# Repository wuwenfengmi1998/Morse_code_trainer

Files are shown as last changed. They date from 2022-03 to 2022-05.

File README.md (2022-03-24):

仓库地址 [Github][1]  
备用仓库 [Git.LMVE][2]  
# 莫尔斯电码练习器

## 项目背景
对业余无线电产生了一些兴趣，想学习莫尔斯电码。买一个练习器太贵了，所以打算做一个。

# 开发中
## 硬件&功能
* STM32L03x 32PinIO 48MHz 
* Buzzer 带静音电路
* 3.5 Audio接口 输入与输出 输出电容耦合
* 12864OLED
* EEPROM
* 编码器开关 开机电路
* TYPEC USB 充放电路 带串口芯片
* 电池 电量检测电路

## 软件功能
* 基础UI
* 莫尔斯电码输入识别 手动键与自动键
* 蜂鸣器播放 音频口输出 可静音
* 可设置速率
* 电池电量检测

  [1]: https://github.com/wuwenfengmi1998/Morse_code_trainer
  [2]: https://git.lmve.net/kevin/morse_code_trainer

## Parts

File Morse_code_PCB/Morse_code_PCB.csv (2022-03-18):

ID | 指示符 | 软件包 | 数量 | 名称 | 供应商和参考
1 | C2,C3 | C_0603_1608Metric | 2 | 10nF
2 | R19,R21,R20,R18,R17,R2,R16,R3,R4 | R_0603_1608Metric | 9 | 10K
3 | C4,C9,C7,C11 | C_0805_2012Metric | 4 | 104
4 | Q3,Q1 | SOT-23 | 2 | AO3400A
5 | BZ1 | Buzzer_TDK_PS1240P02BT_D12.2mm_H6.5mm | 1 | Buzzer
6 | J4 | SIP-2 | 1 | Conn_01x02_Female
7 | D1,D5,D4 | D_SOD-523 | 3 | 1N4148WT
8 | D2,D3,D6 | LED_0603_1608Metric | 3 | LED
9 | R8,R7,R6,R9 | R_0603_1608Metric | 4 | 20K
10 | L1 | L_0805_2012Metric | 1 | 100mH
11 | SW1 | EC11 | 1 | RotaryEncoder_Switch
12 | C8,C5,C13,C6,C12,C10 | C_1206_3216Metric | 6 | 10uF
13 | R13,R23,R1,R22 | R_0603_1608Metric | 4 | 1K
14 | U3 | SOT-23-5 | 1 | MCP73831-2-OT
15 | U2 | OLED12864 | 1 | OLED_12864
16 | J1 | USB_C_Receptacle_HRO_TYPE-C-31-M-12 | 1 | USB_C_Receptacle_USB2.0
17 | R24,R14 | R_0603_1608Metric | 2 | 510
18 | J3 | Jack_3.5mm_PJ320D_Horizontal | 1 | OUTPUT
19 | C1 | C_0805_2012Metric | 1 | 100nF
20 | U4 | MSOP-10_3x3mm_P0.5mm | 1 | CH340E
21 | R12,R11 | R_0603_1608Metric | 2 | 100
22 | R10,R5 | R_0603_1608Metric | 2 | 2K
23 | U1 | TSSOP-20_4.4x6.5mm_P0.65mm | 1 | STM32F030F4Px
24 | Q4,Q2 | SOT-23 | 2 | AO3401A
25 | U6 | SOT-23-5 | 1 | 24AA02-OT
26 | U5 | SOT-23-5 | 1 | LP5907MFX-3.3
27 | R15 | R_0402_1005Metric | 1 | *R0
28 | J5 | SIP-4 | 1 | Conn_01x04_Female
29 | J2 | Jack_3.5mm_PJ320D_Horizontal | 1 | INPUT

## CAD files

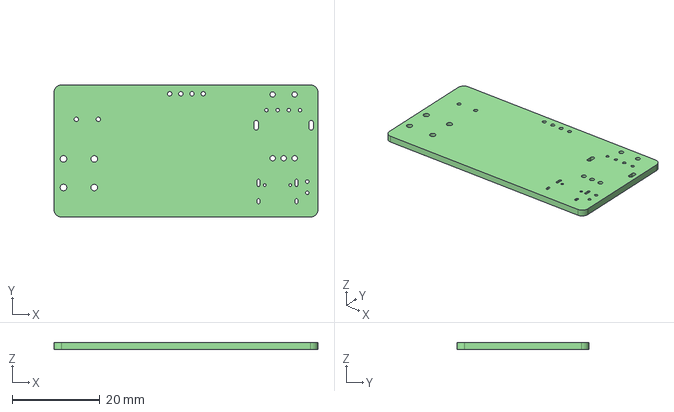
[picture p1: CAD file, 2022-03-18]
Morse_code_PCB/Morse_code_PCB.step
60.0 x 30.0 x 1.60 mm

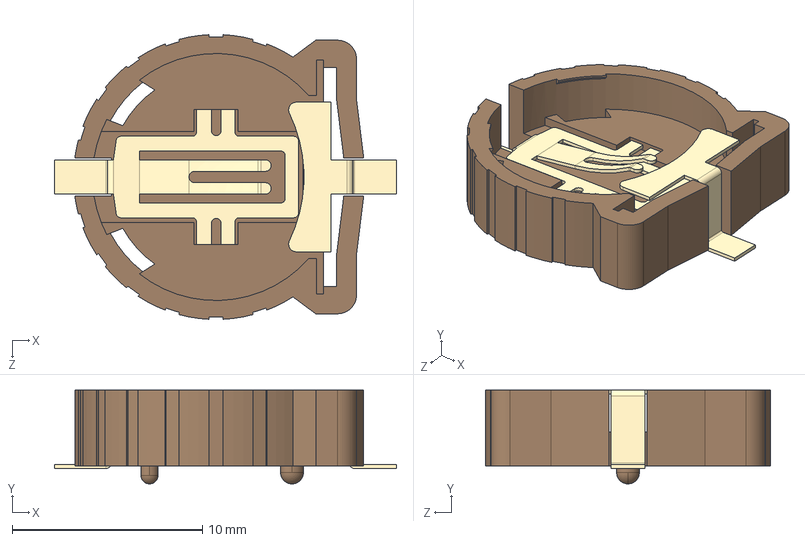
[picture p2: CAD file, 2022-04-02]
Morse_code_PCB/steps/BC501SM.step
18.0 x 4.94 x 15.0 mm

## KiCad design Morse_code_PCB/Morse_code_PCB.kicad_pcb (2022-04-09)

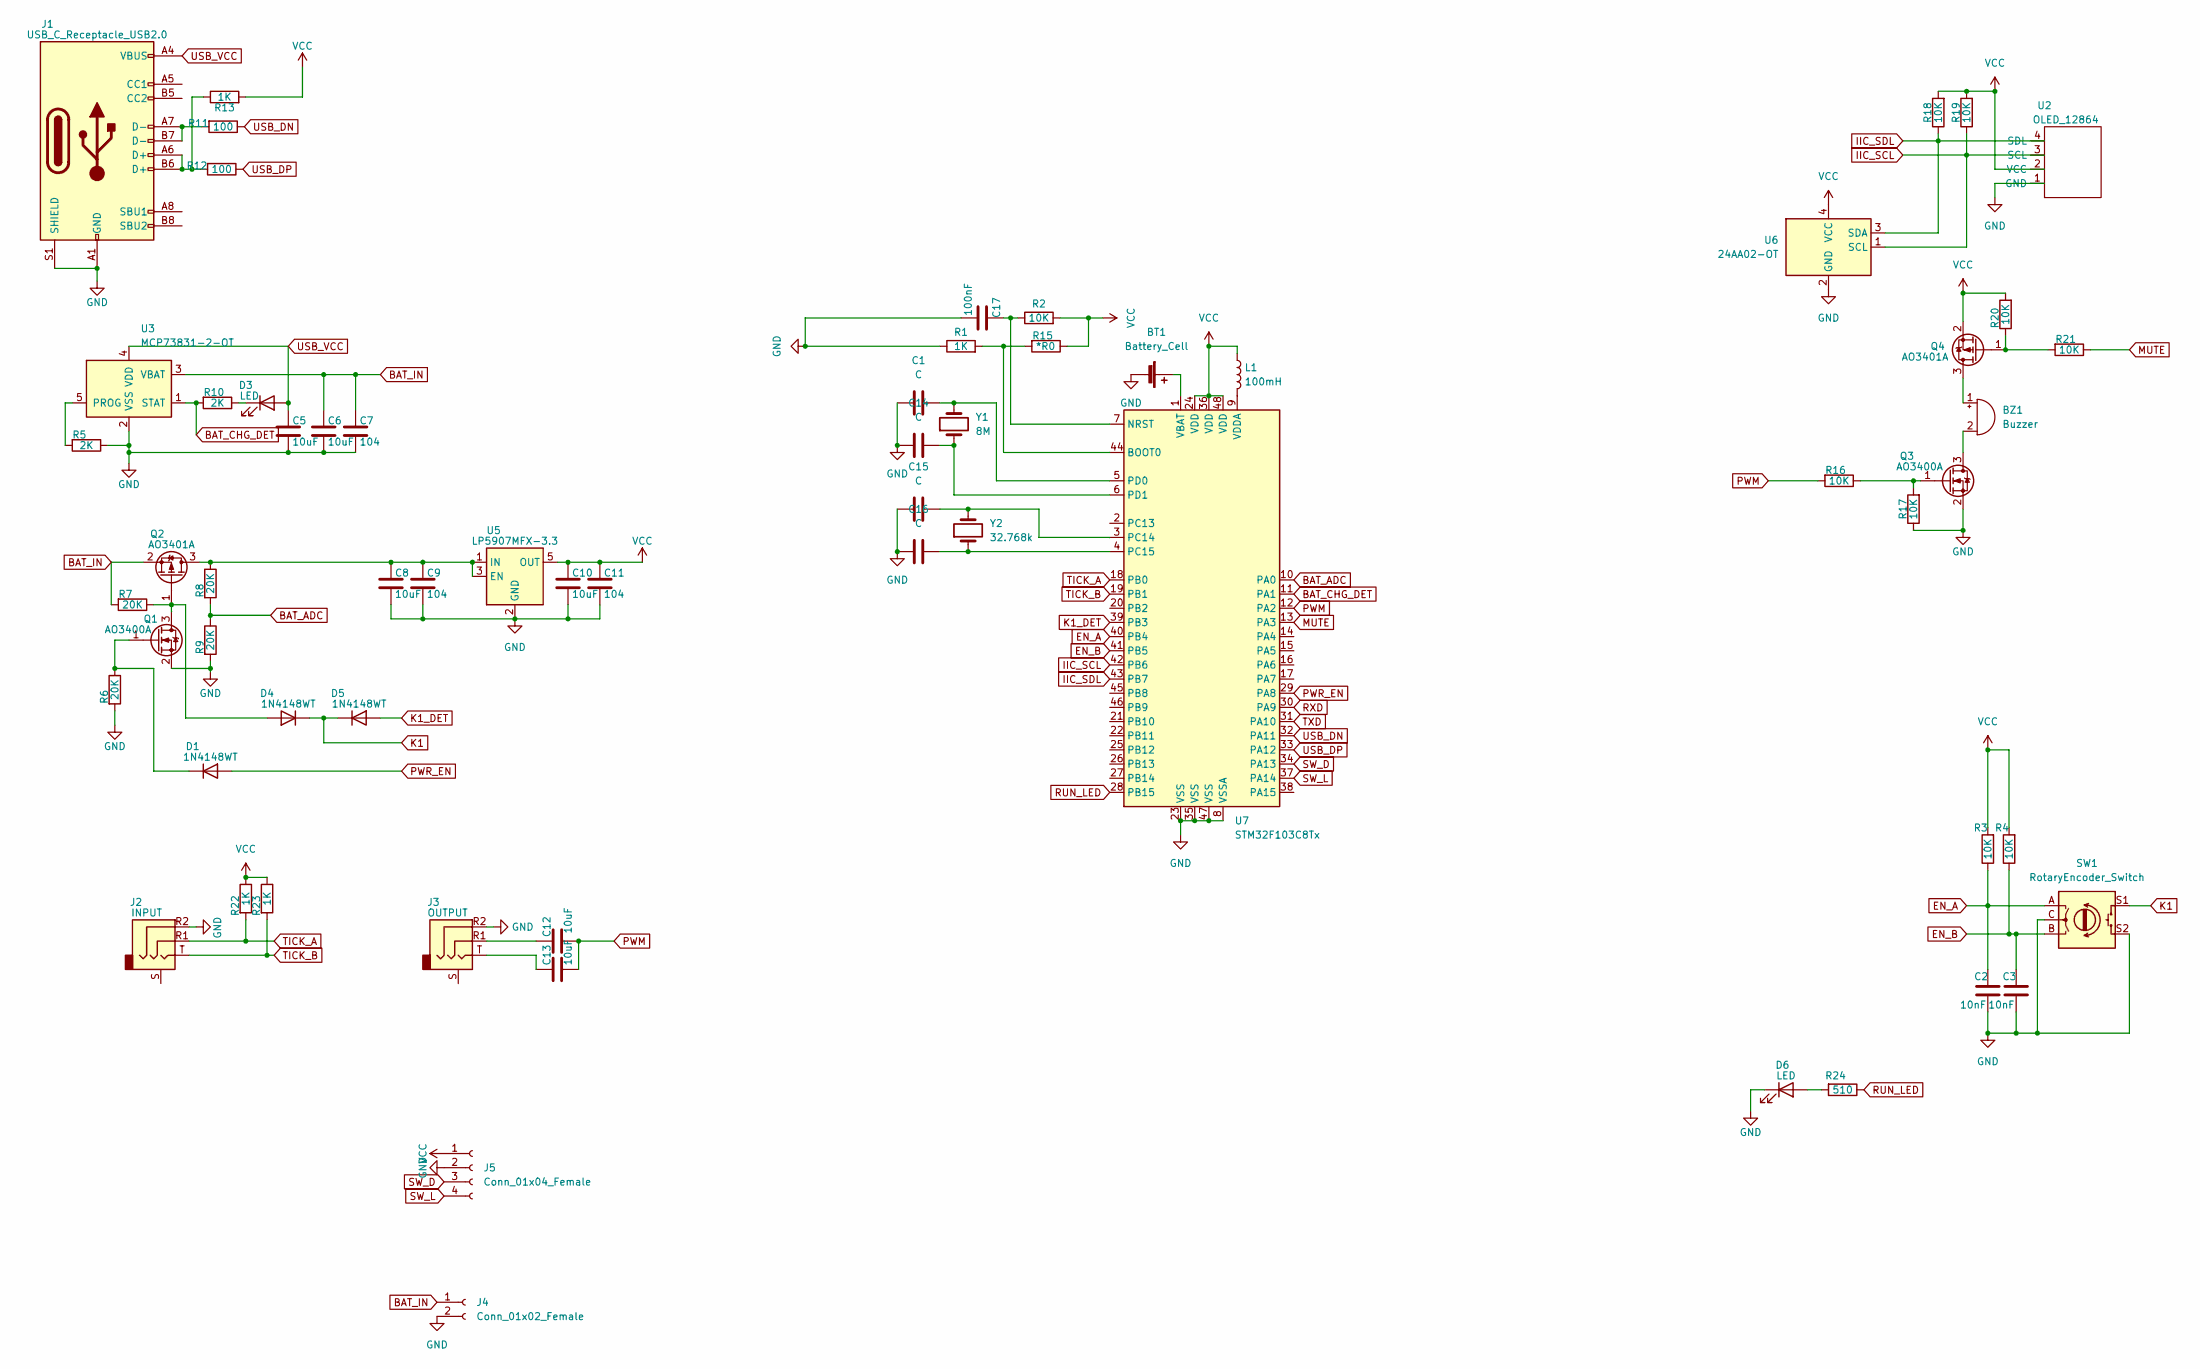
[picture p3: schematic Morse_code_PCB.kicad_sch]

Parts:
BT1: Battery_Cell; BAT_BC501SM
BZ1: Buzzer; Buzzer_TDK_PS1240P02BT_D12.2mm_H6.5mm
C1, C14, C15, C16: C; C_0402_1005Metric_Pad0.74x0.62mm_HandSolder
C2, C3: 10nF; C_0603_1608Metric
C5, C6, C8, C10, C12, C13: 10uF; C_1206_3216Metric
C7, C9, C11: 104; C_0805_2012Metric
C17: 100nF; C_0805_2012Metric
D1, D4, D5: 1N4148WT; D_SOD-523
D3, D6: LED; LED_0603_1608Metric
J1: USB_C_Receptacle_USB2.0; USB_C_Receptacle_HRO_TYPE-C-31-M-12
J2: INPUT; Jack_3.5mm_PJ320D_Horizontal
J3: OUTPUT; Jack_3.5mm_PJ320D_Horizontal
J4: Conn_01x02_Female; SIP-2
J5: Conn_01x04_Female; SIP-4
L1: 100mH; L_0805_2012Metric
Q1, Q3: AO3400A; SOT-23
Q2, Q4: AO3401A; SOT-23
R1, R13, R22, R23: 1K; R_0603_1608Metric
R2, R3, R4, R16, R17, R18, R19, R20, R21: 10K; R_0603_1608Metric
R5, R10: 2K; R_0603_1608Metric
R6, R7, R8, R9: 20K; R_0603_1608Metric
R11, R12: 100; R_0603_1608Metric
R15: *R0; R_0402_1005Metric
R24: 510; R_0603_1608Metric
SW1: RotaryEncoder_Switch; EC11
U2: OLED_12864; OLED12864
U3: MCP73831-2-OT; SOT-23-5
U5: LP5907MFX-3.3; SOT-23-5
U6: 24AA02-OT; SOT-23-5
U7: STM32F103C8Tx; LQFP-48_7x7mm_P0.5mm
Y1: 8M; Crystal_SMD_5032-2Pin_5.0x3.2mm
Y2: 32.768k; Crystal_SMD_3215-2Pin_3.2x1.5mm

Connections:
BAT_ADC: R8.2, R9.1, U7.10 (PA0)
BAT_CHG_DET: R10.2, U3.1 (STAT), U7.11 (PA1)
BAT_IN: C6.1, C7.1, J4.1, Q2.2 (S), R7.2, U3.3 (VBAT)
EN_A: C2.1, R3.1, SW1.A, U7.40 (PB4)
EN_B: C3.1, R4.1, SW1.B, U7.41 (PB5)
GND: BT1.2 (-), C1.1, C2.2, C3.2, C5.2, C6.2, C7.2, C8.2, C9.2, C10.2, C11.2, C14.1, C15.1, C16.1, C17.2, D6.1 (K), J1.A1 (GND), J1.A12 (GND), J1.B1 (GND), J1.B12 (GND), J1.S1 (SHIELD), J2.R2, J3.R2, J4.2, J5.2, Q1.2 (S), Q3.2 (S), R1.1, R5.1, R6.2, R9.2, R17.1, SW1.C, SW1.S2, U2.1 (GND), U3.2 (VSS), U5.2 (GND), U6.2 (GND), U7.8 (VSSA), U7.23 (VSS), U7.35 (VSS), U7.47 (VSS)
IIC_SCL: R19.1, U2.3 (SCL), U6.1 (SCL), U7.42 (PB6)
IIC_SDL: R18.1, U2.4 (SDL), U6.3 (SDA), U7.43 (PB7)
K1: D4.1 (K), D5.1 (K), SW1.S1
K1_DET: D5.2 (A), U7.39 (PB3)
MUTE: R21.1, U7.13 (PA3)
unnamed: BT1.1 (+), U7.1 (VBAT)
unnamed: BZ1.1 (-), Q4.3 (D)
unnamed: BZ1.2 (+), Q3.3 (D)
unnamed: C8.1, C9.1, Q2.3 (D), R8.1, U5.1 (IN), U5.3 (EN)
unnamed: C12.1, J3.R1
unnamed: C13.1, J3.T
unnamed: D1.1 (K), Q1.1 (G), R6.1
unnamed: D3.1 (K), R10.1
unnamed: D4.2 (A), Q1.3 (D), Q2.1 (G), R7.1
unnamed: D6.2 (A), R24.2
unnamed: Q3.1 (G), R16.1, R17.2
unnamed: Q4.1 (G), R20.1, R21.2
unnamed: R5.2, U3.5 (PROG)
unnamed: J1.A7 (D-), J1.B7 (D-), R11.2
unnamed: J1.A6 (D+), J1.B6 (D+), R12.2, R13.1
unnamed: C15.2, U7.3 (PC14), Y2.2
unnamed: C16.2, U7.4 (PC15), Y2.1
unnamed: C1.2, U7.5 (PD0), Y1.2
unnamed: C14.2, U7.6 (PD1), Y1.1
unnamed: C17.1, R2.1, U7.7 (NRST)
unnamed: L1.2, U7.9 (VDDA)
unnamed: R1.2, R15.2, U7.44 (BOOT0)
PWM: C12.2, C13.2, R16.2, U7.12 (PA2)
PWR_EN: D1.2 (A), U7.29 (PA8)
RUN_LED: R24.1, U7.28 (PB15)
RXD: U7.30 (PA9)
SW_D: J5.3, U7.34 (PA13)
SW_L: J5.4, U7.37 (PA14)
TICK_A: J2.R1, R22.2, U7.18 (PB0)
TICK_B: J2.T, R23.2, U7.19 (PB1)
TXD: U7.31 (PA10)
USB_DN: R11.1, U7.32 (PA11)
USB_DP: R12.1, U7.33 (PA12)
USB_VCC: C5.1, D3.2 (A), J1.A4 (VBUS), J1.A9 (VBUS), J1.B4 (VBUS), J1.B9 (VBUS), U3.4 (VDD)
VCC: C10.1, C11.1, J5.1, L1.1, Q4.2 (S), R2.2, R3.2, R4.2, R13.2, R15.1, R18.2, R19.2, R20.2, R22.1, R23.1, U2.2 (VCC), U5.5 (OUT), U6.4 (VCC), U7.24 (VDD), U7.36 (VDD), U7.48 (VDD)

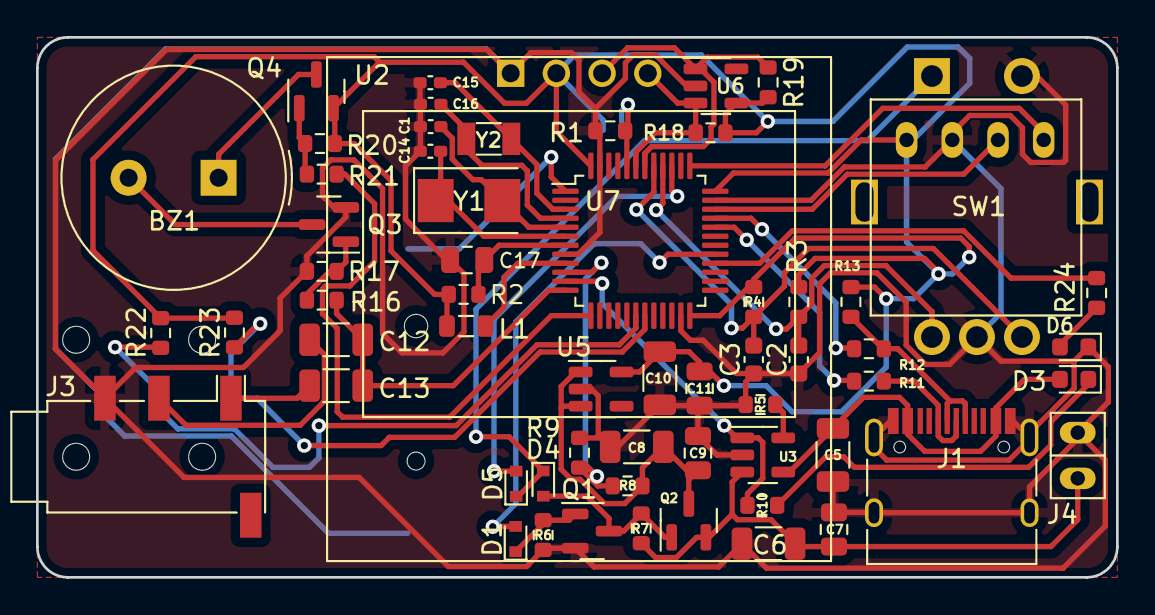
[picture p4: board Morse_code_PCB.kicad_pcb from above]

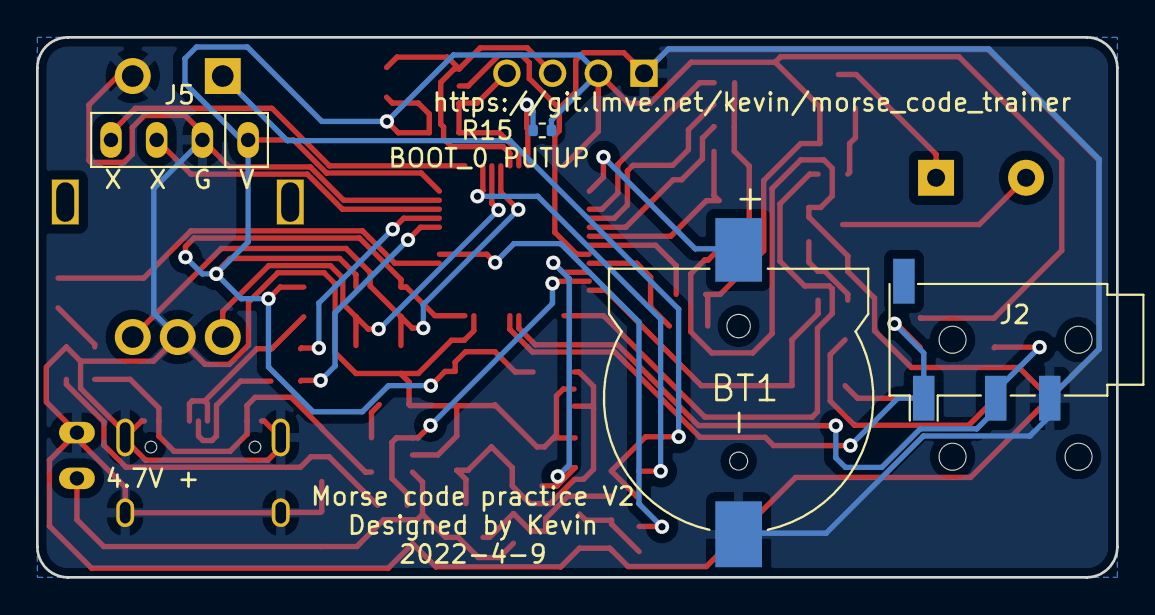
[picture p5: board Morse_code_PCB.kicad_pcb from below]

Board: 2 copper layers, 60.0 x 30.0 mm, 64 parts (4 on the bottom side), 44 nets.

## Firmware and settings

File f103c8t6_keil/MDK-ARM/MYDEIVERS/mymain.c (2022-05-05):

/*
 * mymain.c
 *
 *  Created on: 2022年4月15日
 *      Author: wuwen
 */
#include "mymain.h"




#define morse_play_t1 50
#define morse_play_t2 (morse_play_t1*3)
#define morse_play_hz 1000







button  B1,TACKA,TACKB;//创建一个按钮
encoder E1;//创建一个编码器
int mode=0;
uint32_t run_tick=0,jump_tick=0;
char str[16];
uint16_t fps=0,fps_=0;
char sys_lan=0;

int encode_c=0;

int test_code=0;

menu menu_main=
{
		"Back\nInput mode\nBuzzer\nDisplay\nLanguage\nAbout",
	"返回\n输入模式\n蜂鸣器\n显示\n语言\n关于",

		0,0
};

void di()
{
	BUZZER_PLAY_NOTES(morse_play_hz,morse_play_t1,50);
	BUZZER_PLAY_NOTES(0,morse_play_t1,0);
	mo_di();
}

void da()
{
	BUZZER_PLAY_NOTES(morse_play_hz,morse_play_t2,50);
	BUZZER_PLAY_NOTES(0,morse_play_t1,0);
	mo_da();
}

void mymain()
{
	PWR_EN(1);
	

	
	
	OLED_Init();//屏幕初始化
	HAL_TIM_PWM_Start(&htim2,TIM_CHANNEL_3);//启动n通道的pwm
	HAL_TIM_Base_Start_IT(&htim3);
	BUZZER_PLAY_INIT();
	MUTE(0);

	BUZZER_PLAY_NOTES(1000,1000,50);
	
	B1.config_longtimes=1;//启用B1按钮的长按检测
	
	while(1)
	{
		GEI_BUTTON_CODE(&B1,en_c());//循环更新按钮
		encode_c=GET_ENCODE(&E1);
		
		switch(mode)
		{
			case 0:
				//启动跳转模式
				//用于读取系统配置后跳转到其他程序
			
				mode=1;
				break;
			case 1:
				//主界面
				GEI_BUTTON_CODE(&TACKA,tack_a());
				GEI_BUTTON_CODE(&TACKB,tack_b());
				if(encode_c>0||TACKB.code!=0)
				{
					di();
				}
				if(encode_c<0||TACKA.code!=0)
				{
					da();
				}			
				OLED_Str(0,0,8,moser_buff,1);

			
				fps_++;
				sprintf(str,"FPS:%d",fps);
				OLED_Str(0,56,8,str,1);
			
				if(B1.code==255)
				{
					mode=2;
					jump_tick=HAL_GetTick()+10000;
				}
				
				break;
			case 2:
				//菜单界面
				if(encode_c!=0)
				{
					jump_tick=HAL_GetTick()+10000;
				}
				switch(SHOW_MENU(&menu_main,encode_c,B1.code,sys_lan))
				{
					case 0:
						mode=1;
						break;
				}
				if(HAL_GetTick()>jump_tick){mode=1;}
				break;
		
		}

		
		mo_server();
		BUZZER_PLAY_SERVER();
		OLED_Cache_to_hardware();//刷新屏幕
		
		if(HAL_GetTick()>run_tick)
		{
			run_tick+=1000;
			RUNLED_TICK();
			fps=fps_;
			fps_=0;
		}
	
	}
}

//外部中断回调
void HAL_GPIO_EXTI_Callback(uint16_t GPIO_Pin)
{

	switch (GPIO_Pin)//中断线监测
	{
  	case en_a_Pin: //编码器A脚 这个脚在config是只监测下降沿
			switch(HAL_GPIO_ReadPin(en_b_GPIO_Port,en_b_Pin))//监测编码器B脚
			{
				case 1://通过监测B脚的状态识别正反转
					E1.code+=1;
					E1.move_flag=1;//发生旋转的标记
					
					break;
				case 0:
					E1.code-=1;
					E1.move_flag=1;
					
					break;
			}
		break;
/*
		//外部电键输入
		case tack_a_Pin:
			switch(tack_a())
			{
				case 0:
					//di();
					break;
				case 1:
					break;
			}
		break;
		case tack_b_Pin:
			switch(tack_b())
			{
				case 0:
					//da();
					break;
				case 1:
					break;
			}
		break;
		
		
		case en_c_Pin://编码器C脚 按钮
			switch(en_c())//监测是上升沿还是下降沿
			{
				case 0:
					
					//mo_one_tick(0);
					break;
				case 1:
					
					//mo_one_tick(1);
					break;
			}
			break;
*/			

  	default:
  	break;

  	//__HAL_GPIO_EXTI_CLEAR_IT(GPIO_Pin);
  }
}



void HAL_TIM_PeriodElapsedCallback(TIM_HandleTypeDef *htim)//1ms
{
    if (htim == (&htim3))
		{
		
		}
}

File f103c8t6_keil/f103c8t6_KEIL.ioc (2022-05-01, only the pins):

Mcu.UserName=STM32F103C8Tx
PA13.Signal=SYS_JTMS-SWDIO
PA14.Signal=SYS_JTCK-SWCLK
PA2.Signal=S_TIM2_CH3
PA3.GPIO_Label=mute
PA3.Signal=GPIO_Output
PA8.GPIO_Label=pwr_en
PA8.Signal=GPIO_Output
PB0.GPIO_Label=tack_a
PB0.Signal=GPXTI0
PB1.GPIO_Label=tack_b
PB1.Signal=GPXTI1
PB12.GPIO_Label=run_led2
PB12.Signal=GPIO_Output
PB15.GPIO_Label=run_led
PB15.Signal=GPIO_Output
PB3.GPIO_Label=en_c
PB3.Signal=GPXTI3
PB4.GPIO_Label=en_a
PB4.Signal=GPXTI4
PB5.GPIO_Label=en_b
PB5.Signal=GPIO_Input
PB6.Signal=I2C1_SCL
PB7.Signal=I2C1_SDA
PC14-OSC32_IN.Signal=RCC_OSC32_IN
PC15-OSC32_OUT.Signal=RCC_OSC32_OUT
PD0-OSC_IN.Signal=RCC_OSC_IN
PD1-OSC_OUT.Signal=RCC_OSC_OUT

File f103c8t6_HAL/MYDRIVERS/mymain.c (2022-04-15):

/*
 * mymain.c
 *
 *  Created on: 2022年4月15日
 *      Author: wuwen
 */
#include "mymain.h"
#include "hread_interface.h"

void mymain()
{


	//HAL_GPIO_WritePin(run_led_GPIO_Port, run_led_Pin, 1);
	//OLED_Init();
	//OLED_ShowStr(0,0,"test");
	while(1)
	{
		HAL_GPIO_WritePin(run_led_GPIO_Port, run_led_Pin, 1);
		HAL_GPIO_WritePin(run_led2_GPIO_Port, run_led2_Pin, 1);
		HAL_Delay(100);
		HAL_GPIO_WritePin(run_led_GPIO_Port, run_led_Pin, 0);
		HAL_GPIO_WritePin(run_led2_GPIO_Port, run_led2_Pin, 0);
		HAL_Delay(100);
	}
}

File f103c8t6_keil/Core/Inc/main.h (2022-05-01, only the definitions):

#define mute_Pin GPIO_PIN_3
#define mute_GPIO_Port GPIOA
#define tack_a_Pin GPIO_PIN_0
#define tack_a_GPIO_Port GPIOB
#define tack_a_EXTI_IRQn EXTI0_IRQn
#define tack_b_Pin GPIO_PIN_1
#define tack_b_GPIO_Port GPIOB
#define tack_b_EXTI_IRQn EXTI1_IRQn
#define run_led2_Pin GPIO_PIN_12
#define run_led2_GPIO_Port GPIOB
#define run_led_Pin GPIO_PIN_15
#define run_led_GPIO_Port GPIOB
#define pwr_en_Pin GPIO_PIN_8
#define pwr_en_GPIO_Port GPIOA
#define en_c_Pin GPIO_PIN_3
#define en_c_GPIO_Port GPIOB
#define en_c_EXTI_IRQn EXTI3_IRQn
#define en_a_Pin GPIO_PIN_4
#define en_a_GPIO_Port GPIOB
#define en_a_EXTI_IRQn EXTI4_IRQn
#define en_b_Pin GPIO_PIN_5
#define en_b_GPIO_Port GPIOB

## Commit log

2022-03-14 新建工程 Signed-off-by: kevin <kevin@lmve.net>
    [Morse_code_PCB.kicad_pcb, Morse_code_PCB.kicad_sch]
2022-03-14 画了一点PCB Signed-off-by: kevin <kevin@lmve.net>
    [Morse_code_PCB.kicad_pcb, Morse_code_PCB.kicad_sch]
2022-03-15 updata PCB Signed-off-by: kevin <kevin@lmve.net>
    [Morse_code_PCB.kicad_pcb, Morse_code_PCB.kicad_sch]
2022-03-15 输入引脚 Signed-off-by: kevin <kevin@lmve.net>
2022-03-15 屏蔽一些内容 Signed-off-by: kevin <kevin@lmve.net>
    [Morse_code_PCB.kicad_pcb]
2022-03-15 画了个12864OLED封装 Signed-off-by: kevin <kevin@lmve.net>
    [Morse_code_PCB.kicad_pcb, Morse_code_PCB.kicad_sch]
2022-03-16 摸鱼画了一点 Signed-off-by: kevin <kevin@lmve.net>
    [Morse_code_PCB.kicad_sch]
2022-03-16 updata Signed-off-by: kevin <kevin@lmve.net>
    [Morse_code_PCB.kicad_pcb, Morse_code_PCB.kicad_sch]
2022-03-16 updata PCB
    [Morse_code_PCB.kicad_sch]
2022-03-17 又是12点了，下班后累的不想动，随便折腾一会又该睡觉了 明天摸鱼画吧
    画好了电源部分。。
    [Morse_code_PCB.kicad_pcb]
2022-03-18 PCB画完 Signed-off-by: kevin <kevin@lmve.net>
    [Morse_code_PCB.kicad_pcb, Morse_code_PCB.kicad_sch]
2022-03-18 step Signed-off-by: kevin <kevin@lmve.net>
    [Morse_code_PCB.step]
2022-03-18 打板测试 Signed-off-by: kevin <kevin@lmve.net>
    [Morse_code_PCB-B_Cu.gbr, Morse_code_PCB-B_Mask.gbr, Morse_code_PCB-B_Paste.gbr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]
2022-03-25 部分焊接完成，开始调试程序 Signed-off-by: kevin <kevin@lmve.net>
2022-03-27 OLED驱动 RAM AND FLASH不是很够，只能直接读写屏幕 Signed-off-by: kevin <kevin@lmve.net>
2022-03-27 显示字符串 Signed-off-by: kevin <kevin@lmve.net>
2022-03-28 获取引脚信号 Signed-off-by: kevin <kevin@lmve.net>
2022-03-28 解码 Signed-off-by: kevin <kevin@lmve.net>
2022-03-28 上拉引脚 Signed-off-by: kevin <kevin@lmve.net>
2022-04-02 内存写满了
2022-04-02 PCB0.5版 Signed-off-by: kevin <kevin@lmve.net>
2022-04-02 PCB updata Signed-off-by: kevin <kevin@lmve.net>
    [BC501SM.step, Morse_code_PCB.kicad_pcb, Morse_code_PCB.kicad_sch]
2022-04-15 同时安装keil和cubeide后cubeide编译出来的玩意一直无法运行。被迫用keil开发 Signed-off-by: kevin <kevin@lmve.net>
2022-04-15 OLED 驱动 Signed-off-by: kevin <kevin@lmve.net>
2022-04-16 绘图函数 Signed-off-by: kevin <kevin@lmve.net>
2022-04-16 屏幕加速显示，静态大概有100帧，动态显示随机数大概30帧 Signed-off-by: kevin <kevin@lmve.net>
2022-04-16 基本功能移植 Signed-off-by: kevin <kevin@lmve.net>
2022-04-28 编码器驱动 菜单功能 Signed-off-by: kevin <kevin@lmve.net>
2022-05-01 输入方式改成中断，开启了两个定时器 Signed-off-by: kevin <kevin@lmve.net>
2022-05-01 按钮中断触发 Signed-off-by: kevin <kevin@lmve.net>
2022-05-02 实现功能 但似乎可以不用中断实现 Signed-off-by: kevin <kevin@lmve.net>
2022-05-05 优化按钮消息循环,同时将按钮改为下降沿触发 Signed-off-by: kevin <kevin@lmve.net>
2022-05-05 优化输入 Signed-off-by: kevin <kevin@lmve.net>
2022-05-05 加一些常量 Signed-off-by: kevin <kevin@lmve.net>

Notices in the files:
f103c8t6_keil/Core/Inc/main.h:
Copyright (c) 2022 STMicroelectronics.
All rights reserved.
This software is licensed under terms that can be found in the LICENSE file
